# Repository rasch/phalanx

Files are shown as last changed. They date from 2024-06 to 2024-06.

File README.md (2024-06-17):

# Phalanx

The Phalanx Keyboard, Version 0.1.0

The [Phalanx] is a <kbd>4</kbd> <kbd>×</kbd> <kbd>3</kbd> <kbd>+</kbd> <kbd>2</kbd>,
*ortholinear*, *staggered*, *split* keyboard.

- Keyboard Maintainer: [rasch](https://github.com/rasch/phalanx)
- Hardware Supported: Phalanx 0.1.0 (stm32f072)
- Hardware Availability: [phalanx]

## Getting Board

Check out [the Phalanx releases page][releases] for the required files to get
PCBs manufactured (`plot.zip`) and/or assembled (`bom.csv` and `cpl.csv`). For
those with soldering abilities, an interactive BOM/CPL HTML file (`ibom.html`)
is provided to aid with self-assembly.

During development, it may be preferable (faster) to run rule checks and test
builds locally. There is a `run` shell script in the root of this repository
that is used by the CI/CD for building releases. This script can be run
directly (`./run pcb`), but it requires the `kicad-cli` 8.0+ release to be
installed. Instead, if `podman` is available, it is recommended to use the
`build` script. This script just runs the `./run` script in the
`kicad/kicad:8.0` container. The build files and reports (ERC/DRC) are placed in
the `dist` directory.

The Phalanx Keyboard, Version 0.1.0

In addition to the parts listed in the BOM, the following will be needed for a
complete keyboard:

- 28 x Kailh Low Profile Choc Switches (PG1350)
- 28 x 1u Choc Keycaps (such as MBK, I prefer the convex keys for the thumbs)
- USB-C cable to connect to device
- RJ45 Ethernet Cable to connect keyboard halves (the monoprice micro slimrun
  patch cable works well, I've used the 6 inch cable)
- Some rubber feet or neoprene adhesive rubber pads to prevent the board from
  sliding all over the place

## Firmware Installation

Download the firmware, `phalanx_default.bin`, from [the Phalanx releases
page][releases]. To flash the keyboard, press the reset button on the PCB to
enter bootloader mode, then run:

```sh
dfu-util -a 0 -d 0483:DF11 -s 0x8000000:leave -D phalanx_default.bin
```

For details on compiling the firmware, please see the [Github Actions
workflow][build].

## Keymap

The base alpha layer is based on the [Engram] layout.

```txt
  B  Y  O  U       L  D  W  V
  C  I  E  A       H  T  S  N
  G  X  J  K       R  M  F  P
            ␣    ⌫
```

[QMK] features such as `Mod-Tap`, `Layers`, `Combos` and `Tap Dance` are
utilized to maximize Phalanx's features with only 27% of the keys from a
standard keyboard. Please visit the [Phalanx website][phalanx] for details of
the layout.

## License

[Solderpad Hardware License v2.1](LICENSE)

[phalanx]: https://www.rasch.co/phalanx
[releases]: https://github.com/rasch/phalanx/releases/
[image]: https://i.imgur.com/y4TYriW.jpg
[image-pcb]: https://i.imgur.com/gtF0UkI.png
[build]: https://github.com/rasch/phalanx/blob/main/.github/workflows/fw.yml
[engram]: https://engram.dev/
[qmk]: https://docs.qmk.fm/#/
[//]: https://en.wikipedia.org/wiki/Phalanx_bone

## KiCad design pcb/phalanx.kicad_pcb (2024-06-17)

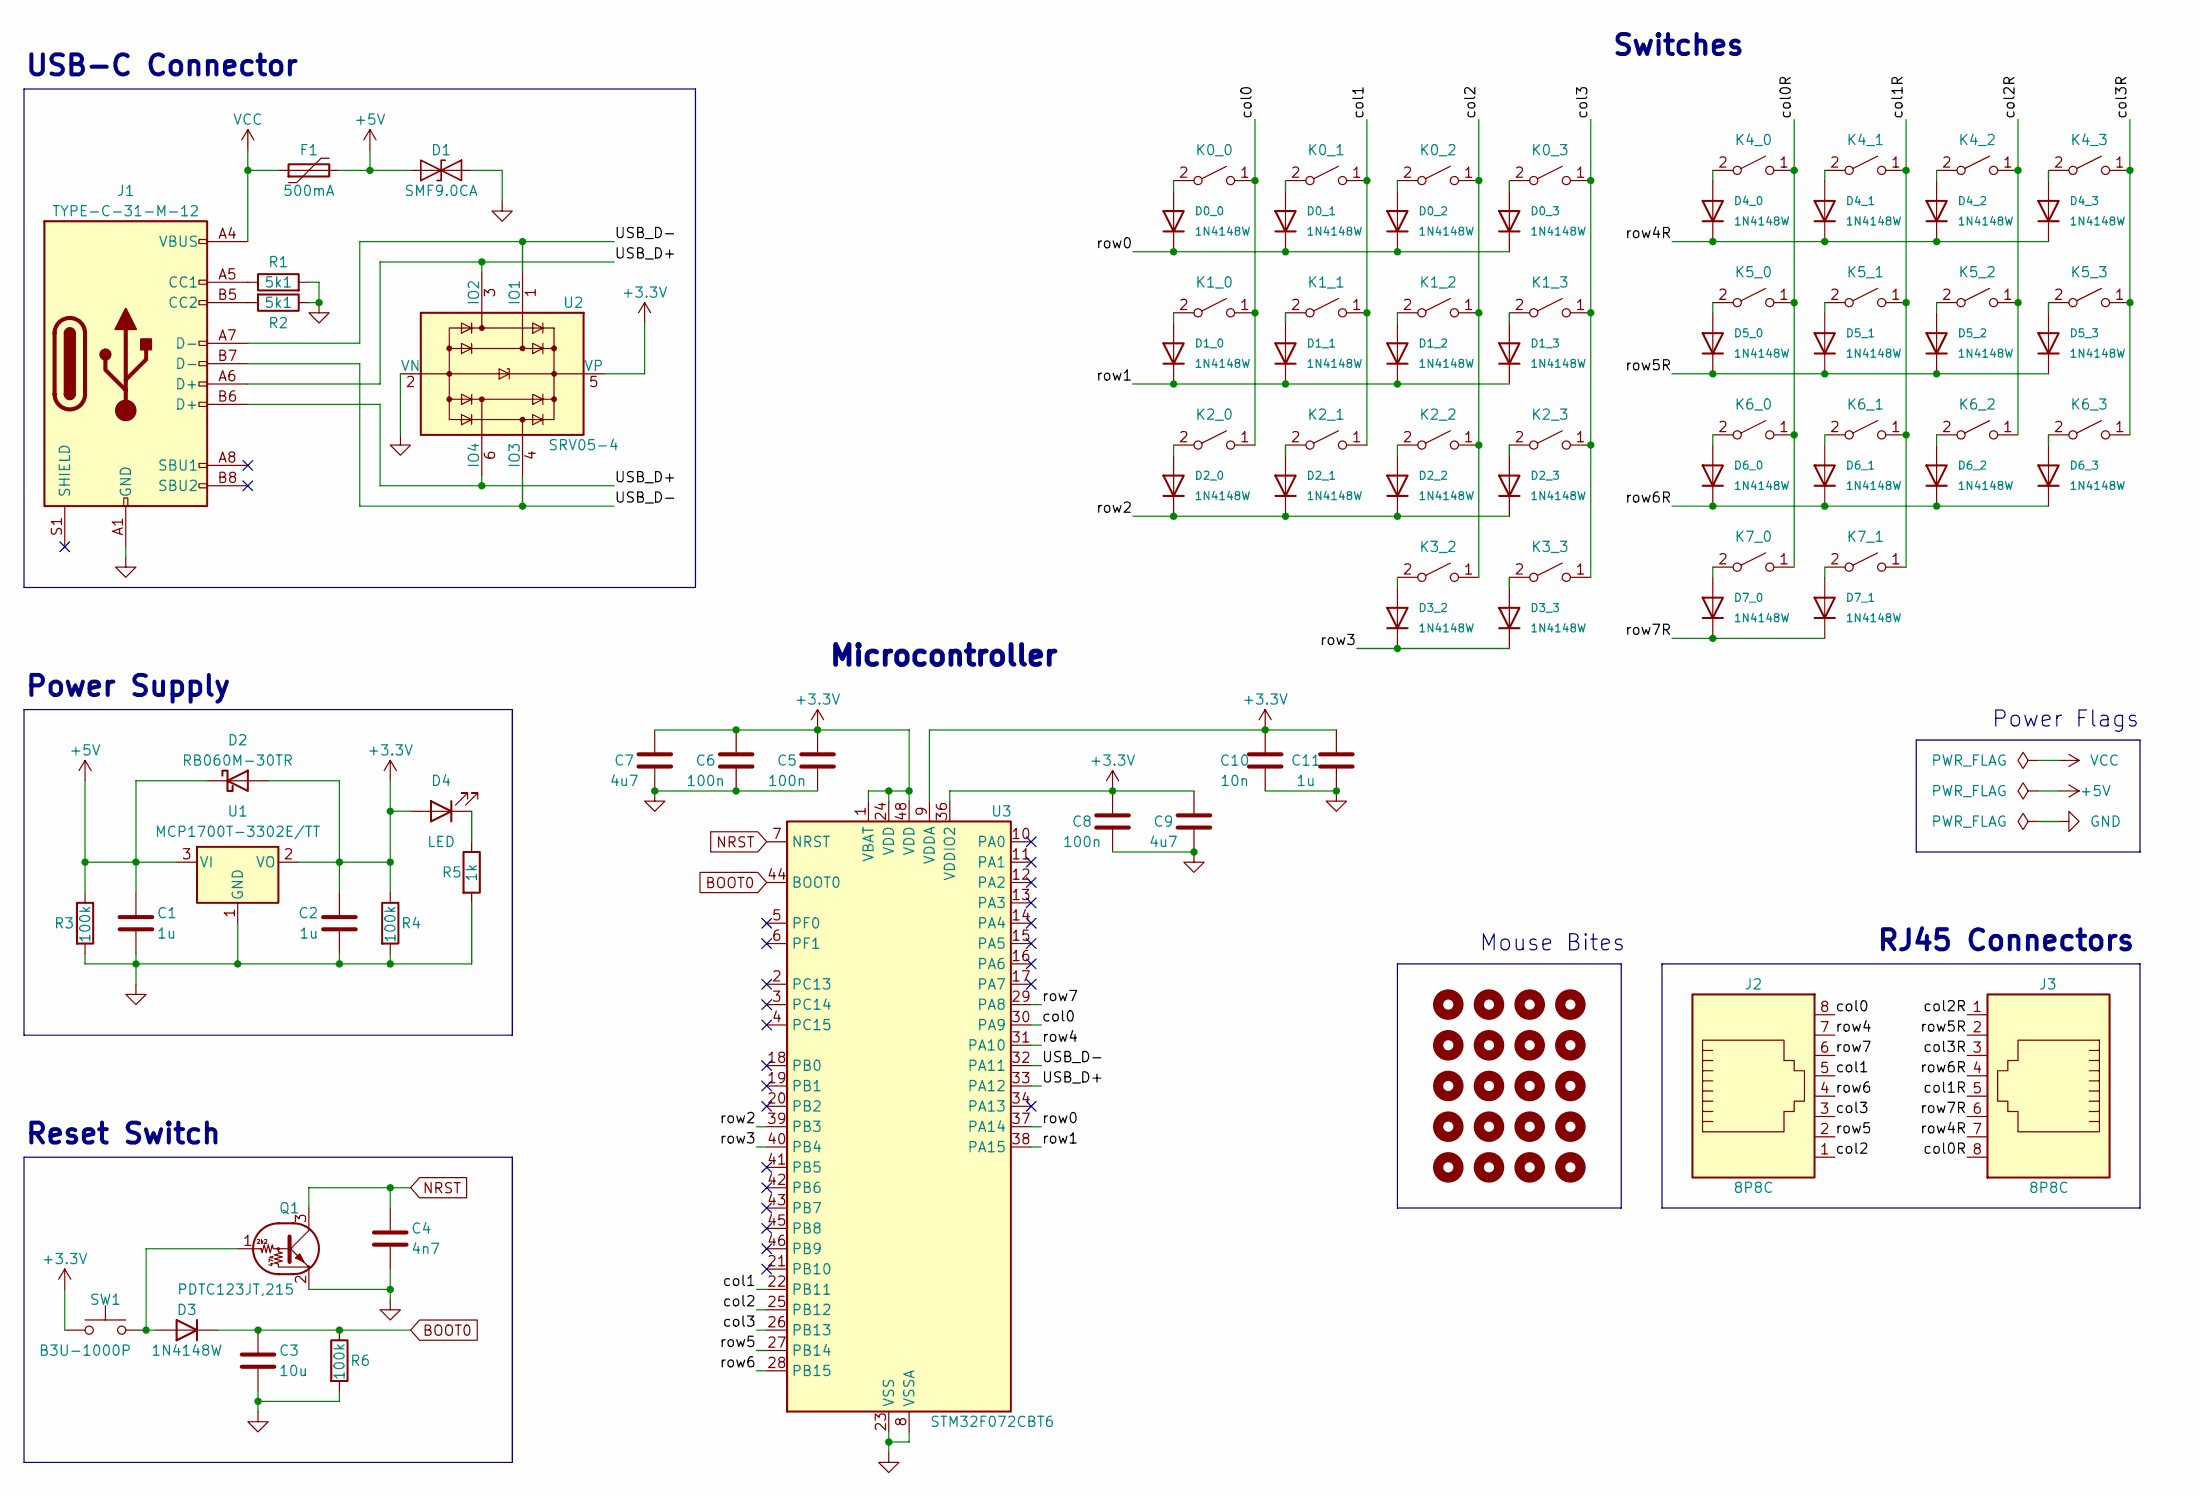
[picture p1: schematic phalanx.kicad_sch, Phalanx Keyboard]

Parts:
C1, C2, C11: 1u; C_0805_2012Metric; Part Name Capacitor; LCSC Part C28323
C3: 10u; C_0805_2012Metric; Part Name Capacitor; LCSC Part C17024
C4: 4n7; C_0805_2012Metric; Part Name Capacitor; LCSC Part C717014
C5, C6, C8: 100n; C_0805_2012Metric; Part Name Capacitor; LCSC Part C49678
C7, C9: 4u7; C_0805_2012Metric; Part Name Capacitor; LCSC Part C87998
C10: 10n; C_0805_2012Metric; Part Name Capacitor; LCSC Part C1710
D0_0, D0_1, D0_2, D0_3, D1_0, D1_1, D1_2, D1_3, D2_0, D2_1, D2_2, D2_3, D3, D3_2, D3_3, D4_0, D4_1, D4_2, D4_3, D5_0, D5_1, D5_2, D5_3, D6_0, D6_1, D6_2, D6_3, D7_0, D7_1: 1N4148W; D_SOD-123; Part Name Diode; LCSC Part C81598
D1: SMF9.0CA; D_SOD-123; Part Name Bidirectional Diode; LCSC Part C435473
D2: RB060M-30TR; D_SOD-123; Part Name Schottky Barrier Diodes; LCSC Part C559324
D4: LED; LED_0603_1608Metric; Part Name Red LED; LCSC Part C84263
F1: 500mA; Fuse_1206_3216Metric; Part Name Polyfuse; LCSC Part C151162
H1, H2, H3, H4, H5, H6, H7, H8, H9, H10, H11, H12, H13, H14, H15, H16, H17, H18, H19, H20: MountingHole; MountingHole_0.5mm
J1: TYPE-C-31-M-12; USB_C_Receptacle_HRO_TYPE-C-31-M-12; Part Name USB C; LCSC Part C165948
J2, J3: 8P8C; RJ45; Part Name RJ45 Receptacle; LCSC Part C2902700
K0_0, K0_1, K0_2, K0_3, K1_0, K1_1, K1_2, K1_3, K2_0, K2_1, K2_2, K2_3, K3_2, K3_3, K4_0, K4_1, K4_2, K4_3, K5_0, K5_1, K5_2, K5_3, K6_0, K6_1, K6_2, K6_3, K7_0, K7_1: SW_KEY; Choc_PG1350_Choc_Spacing
Q1: PDTC123JT,215; SOT-23; Part Name NPN Transistor; LCSC Part C406040
R1, R2: 5k1; R_0805_2012Metric; Part Name Resistor; LCSC Part C27834
R3, R4, R6: 100k; R_0805_2012Metric; Part Name Resistor; LCSC Part C149504
R5: 1k; R_0805_2012Metric; Part Name Resistor; LCSC Part C17513
SW1: B3U-1000P; SW_SPST_B3U-1000P; Part Name Reset Button; LCSC Part C231329
U1: MCP1700T-3302E/TT; SOT-23; Part Name Dropout Regulator; LCSC Part C39051
U2: SRV05-4; SOT-23-6; Part Name TVS Diode Array; LCSC Part C558418
U3: STM32F072CBT6; LQFP-48_7x7mm_P0.5mm; Part Name MCU; LCSC Part C81720

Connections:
+3.3V: C2.1, C5.1, C6.2, C7.1, C8.2, C9.2, C10.2, C11.2, D2.2 (A), D4.2 (A), R4.1, SW1.1, U1.2 (VO), U2.5 (VP), U3.1 (VBAT), U3.9 (VDDA), U3.24 (VDD), U3.36 (VDDIO2), U3.48 (VDD)
+5V: C1.1, D1.1 (A1), D2.1 (K), F1.2, R3.1, U1.3 (VI)
/USB_D+: J1.A6 (D+), J1.B6 (D+), U2.3 (IO2), U2.6 (IO4), U3.33 (PA12)
/USB_D-: J1.A7 (D-), J1.B7 (D-), U2.1 (IO1), U2.4 (IO3), U3.32 (PA11)
/col0: J2.8, K0_0.1 (A), K1_0.1 (A), K2_0.1 (A), U3.30 (PA9)
/col0R: J3.8, K4_0.1 (A), K5_0.1 (A), K6_0.1 (A), K7_0.1 (A)
/col1: J2.5, K0_1.1 (A), K1_1.1 (A), K2_1.1 (A), U3.22 (PB11)
/col1R: J3.5, K4_1.1 (A), K5_1.1 (A), K6_1.1 (A), K7_1.1 (A)
/col2: J2.1, K0_2.1 (A), K1_2.1 (A), K2_2.1 (A), K3_2.1 (A), U3.25 (PB12)
/col2R: J3.1, K4_2.1 (A), K5_2.1 (A), K6_2.1 (A)
/col3: J2.3, K0_3.1 (A), K1_3.1 (A), K2_3.1 (A), K3_3.1 (A), U3.26 (PB13)
/col3R: J3.3, K4_3.1 (A), K5_3.1 (A), K6_3.1 (A)
/row0: D0_0.1 (K), D0_1.1 (K), D0_2.1 (K), D0_3.1 (K), U3.37 (PA14)
/row1: D1_0.1 (K), D1_1.1 (K), D1_2.1 (K), D1_3.1 (K), U3.38 (PA15)
/row2: D2_0.1 (K), D2_1.1 (K), D2_2.1 (K), D2_3.1 (K), U3.39 (PB3)
/row3: D3_2.1 (K), D3_3.1 (K), U3.40 (PB4)
/row4: J2.7, U3.31 (PA10)
/row4R: D4_0.1 (K), D4_1.1 (K), D4_2.1 (K), D4_3.1 (K), J3.7
/row5: J2.2, U3.27 (PB14)
/row5R: D5_0.1 (K), D5_1.1 (K), D5_2.1 (K), D5_3.1 (K), J3.2
/row6: J2.4, U3.28 (PB15)
/row6R: D6_0.1 (K), D6_1.1 (K), D6_2.1 (K), D6_3.1 (K), J3.4
/row7: J2.6, U3.29 (PA8)
/row7R: D7_0.1 (K), D7_1.1 (K), J3.6
BOOT0: C3.2, D3.1 (K), R6.1, U3.44 (BOOT0)
GND: C1.2, C2.2, C3.1, C4.2, C5.2, C6.1, C7.2, C8.1, C9.1, C10.1, C11.1, D1.2 (A2), J1.A1 (GND), J1.A12 (GND), J1.B1 (GND), J1.B12 (GND), Q1.2 (E), R1.2, R2.1, R3.2, R4.2, R5.2, R6.2, U1.1 (GND), U2.2 (VN), U3.8 (VSSA), U3.23 (VSS), U3.35 (VSS), U3.47 (VSS)
NRST: C4.1, Q1.3 (C), U3.7 (NRST)
unnamed: D0_0.2 (A), K0_0.2 (B)
unnamed: D0_1.2 (A), K0_1.2 (B)
unnamed: D0_2.2 (A), K0_2.2 (B)
unnamed: D0_3.2 (A), K0_3.2 (B)
unnamed: D1_0.2 (A), K1_0.2 (B)
unnamed: D1_1.2 (A), K1_1.2 (B)
unnamed: D1_2.2 (A), K1_2.2 (B)
unnamed: D1_3.2 (A), K1_3.2 (B)
unnamed: D2_0.2 (A), K2_0.2 (B)
unnamed: D2_1.2 (A), K2_1.2 (B)
unnamed: D2_2.2 (A), K2_2.2 (B)
unnamed: D2_3.2 (A), K2_3.2 (B)
unnamed: D3.2 (A), Q1.1 (B), SW1.2
unnamed: D3_2.2 (A), K3_2.2 (B)
unnamed: D3_3.2 (A), K3_3.2 (B)
unnamed: D4.1 (K), R5.1
unnamed: D4_0.2 (A), K4_0.2 (B)
unnamed: D4_1.2 (A), K4_1.2 (B)
unnamed: D4_2.2 (A), K4_2.2 (B)
unnamed: D4_3.2 (A), K4_3.2 (B)
unnamed: D5_0.2 (A), K5_0.2 (B)
unnamed: D5_1.2 (A), K5_1.2 (B)
unnamed: D5_2.2 (A), K5_2.2 (B)
unnamed: D5_3.2 (A), K5_3.2 (B)
unnamed: D6_0.2 (A), K6_0.2 (B)
unnamed: D6_1.2 (A), K6_1.2 (B)
unnamed: D6_2.2 (A), K6_2.2 (B)
unnamed: D6_3.2 (A), K6_3.2 (B)
unnamed: D7_0.2 (A), K7_0.2 (B)
unnamed: D7_1.2 (A), K7_1.2 (B)
unnamed: J1.A5 (CC1), R1.1
unnamed: J1.B5 (CC2), R2.2
VCC: F1.1, J1.A4 (VBUS), J1.A9 (VBUS), J1.B4 (VBUS), J1.B9 (VBUS)

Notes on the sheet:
Power Flags
Switches
USB-C Connector
Power Supply
Microcontroller
Reset Switch
RJ45 Connectors
Mouse Bites

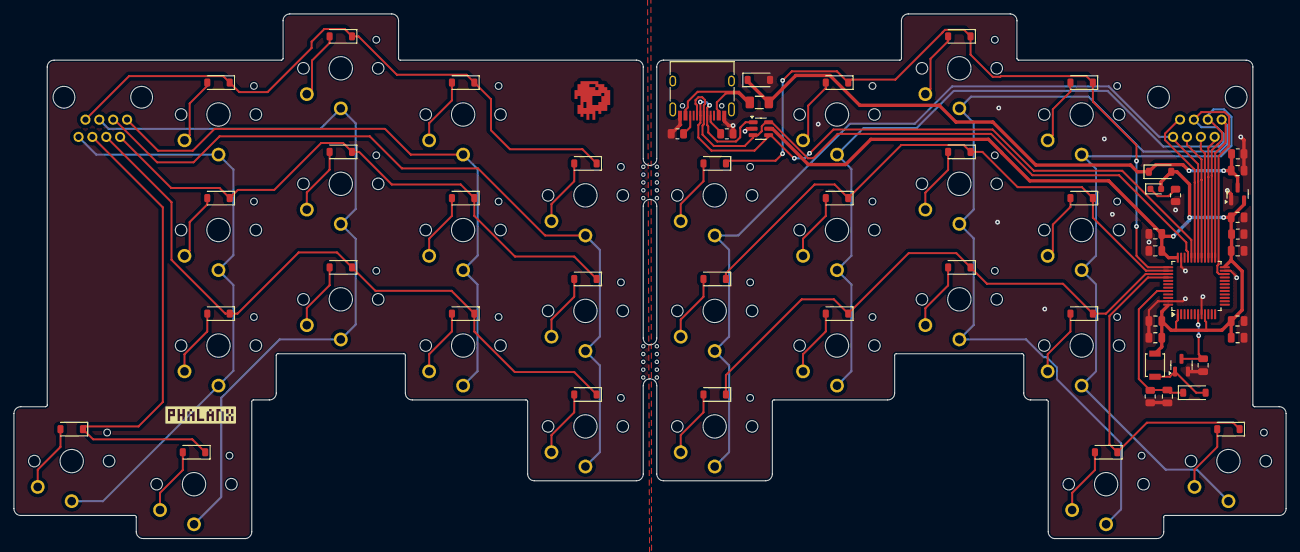
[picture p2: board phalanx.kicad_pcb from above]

Board: 2 copper layers, 187.2 x 77.2 mm, 106 parts (0 on the bottom side), 60 nets.

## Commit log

2023-11-22 🎉 Initial commit
2023-11-29 ✨ Add PCB files and LICENSE
    [phalanx.kicad_pcb, phalanx.kicad_sch]
2023-11-30 🚨 Fix DRC (design rule check) warnings
    [phalanx.kicad_pcb]
2023-12-01 🚸 Add LCSC Part numbers to schematic symbols
    [phalanx.kicad_sch]
2023-12-01 🚚 Rename a couple files
2023-12-01 👷 Add script to generate manufacturing files
2023-12-02 👷 Configure release automation
2023-12-02 📝 Add documentation for PCB releases
2024-03-09 ✨ Add firmware configuration
2024-03-09 ✨ Add updated PCB files
    [phalanx.kicad_pcb, phalanx.kicad_sch]
2024-03-09 🐛 Increase resistance on pwr LED
    [phalanx.kicad_pcb, phalanx.kicad_sch]
2024-03-11 ✨ Add firmware for 18-key option
    Just to try out Ben Vallack's Piano layout
2024-03-11 📚 Update documentation (WIP)
2024-03-18 📚 Start keymap documentation
2024-06-16 📝 Add documentation website with keymap
2024-06-16 📝 Add note about required parts
2024-06-17 📝 Add addional keymap documentation
2024-06-17 🚨 Fix qmk compiler warnings
    Migrate qmk keyboard firmware from info.json to keyboard.json and remove
    empty rules.mk file.
2024-06-17 👷 Switch to kicad stable for CI/build
    The erc and drc reporting is now available in the stable (8.0) version
    of the kicad-cli!
2024-06-17 💚 Fix CI/build
    Update files from KiCad 7 to KiCad 8 and fix all DRC/ERC errors.
    [phalanx.kicad_pcb, phalanx.kicad_sch]
2024-06-17 💚 Fix CI for firmware compilation
2024-06-17 💚 Fix release notes
2026-05-03 📚 Update link to engram layout documentation
    The old link now belongs to an online casino.
